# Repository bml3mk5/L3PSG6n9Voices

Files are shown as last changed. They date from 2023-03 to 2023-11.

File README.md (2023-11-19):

# PSG 6&9声カード for 日立ベーシックマスターレベル3

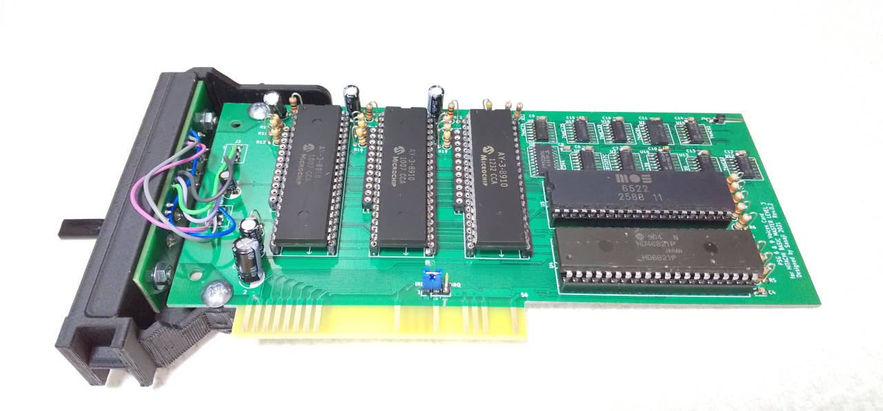
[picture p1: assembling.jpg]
Example of assembling


## フォルダ構成

    BackCover/ ..................... 背面カバーの3Dモデル
      L3BackSide2MJF-Resized.stl ... 背面カバーの3Dモデルファイル
      MegaZero2.0/ ................. Anycube MegaZero 2.0用
    Board/ ......................... 基板設計(KiCAD Version 5)
      main/ ........................ メイン基板
      side/ ........................ サブ基板(背面カバーに取り付ける基板)
      side_with_cover/ ............. 背面カバーを兼ねた基板

 * 3Dモデルから背面カバーを作ったときは、サブ基板を使用します。

-----
# PSG 6&9voices card for HITACHI BASIC MASTER LEVEL 3

## Folders:

    BackCover/ ..................... The 3D model of the back cover
      L3BackSide2MJF-Resized.stl ... The file of the back cover
      MegaZero2.0/ ................. For Anycube MegaZero 2.0
    Board/ ......................... Circuit board design(KiCAD Version 5)
      main/ ........................ The main board
      side/ ........................ The sub board (Attach to the back cover)
      side_with_cover/ ............. The side board which doubles as a back cover

 * When you made the back cover from 3D model, use the sub board.

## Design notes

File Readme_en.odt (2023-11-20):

# PSG6&9Voices Card for HITACHI BASIC MASTER LEVEL3

Designed by Sasaji 2021 Rev. 0.2

This is an extension card for HITACHI BASIC MASTER LEVEL3, markII and mark5. This is equipped with 3 PSGs and you can play with up to 9 voices.


Implementation

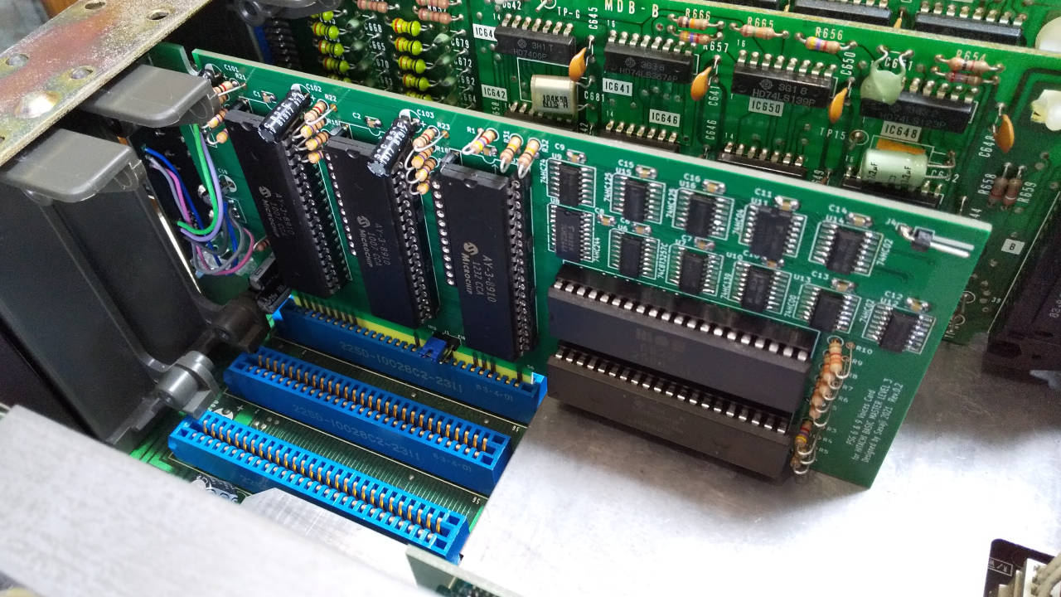
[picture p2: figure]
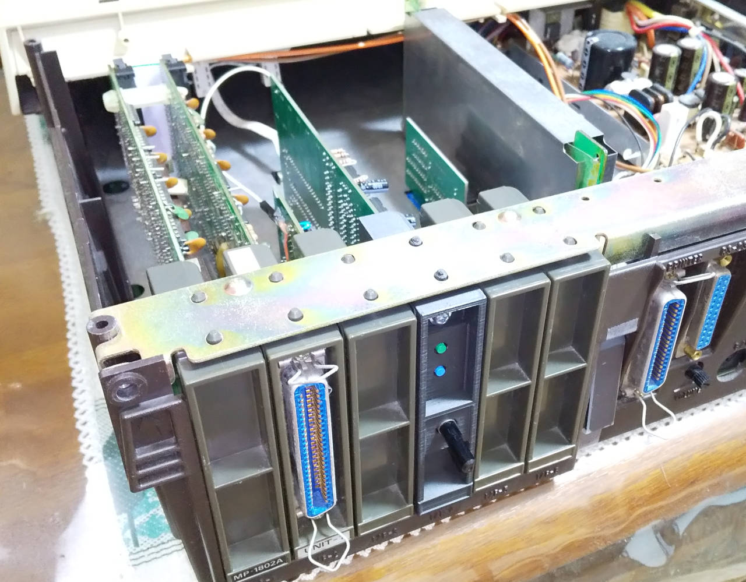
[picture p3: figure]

Installation

This card has two modes to control PSG via PIA and to do it via VIA.

PIA mode | This control two PSGs. You can play up to 6 voices. Supported games: Destroy Alien, The Cockpit
VIA mode | This control three PSGs. You can play up to 9 voices. Supported games: Skipper

You can toggle these modes using a I/O port by software, or buttons on the back side.

When specify from BASIC:

PIA: POKE &HFF34,0

VIA: POKE &HFF34,&H81

# I/O Ports

PIA Register

Address | D7 | D6 | D5 | D4 | D3 | D2 | D1 | D0 | R/W
$FF30 | DA7 | DA6 | DA5 | DA4 | DA3 | DA2 | DA1 | DA0 | R/W | PIA Data Register A Write to PSG
$FF31 | | | | | | | | | R/W | PIA Control Register A
$FF32 | x | x | x | x | x | SEL | BDIR | BC1 | R/W | PIA Data Register B PSG Bus Control
$FF33 | | | | | | | | | R/W | PIA Control Register B

When BDIR = 1 and BC1 = 1, latch register number on PSG.

When BDIR = 1 and BC1 = 0, write data to PSG.

When BDIR = 0 and BC1 = 1, read data from PSG.

SEL : Select PSG1 = 0, Select PSG2 = 1

PIA/VIA Select

Address | D7 | D6 | D5 | D4 | D3 | D2 | D1 | D0 | R/W
$FF34 ($FF35) | CLK | x | x | x | x | x | x | V/P | R/W

V/P … “0”:Select PIA, “1”:Select VIA

CLK … Select clock on PSG “0”: 1MHz “1”:2MHz

VIA Register

Address | D7 | D6 | D5 | D4 | D3 | D2 | D1 | D0 | R/W
$FF70 | x | x | x | PSG3 | PSG2 | PSG1 | BC1 | BDIR | R/W | ORB PSG Bus Control
$FF71 | DA7 | DA6 | DA5 | DA4 | DA3 | DA2 | DA1 | DA0 | R/W | ORA Write to PSG
$FF72 ~ $FF7F | | | | | | | | | | VIA Register See datasheet of VIA for details.

When BDIR = 1 and BC1 = 1, latch register number on PSG.

When BDIR = 1 and BC1 = 0, write data to PSG.

When BDIR = 0 and BC1 = 1, read data from PSG.

PSG1:Select PSG1=1

PSG2:Select PSG2=1

PSG3:Select PSG3=1

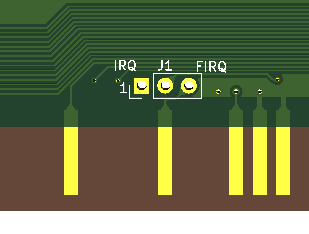
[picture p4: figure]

# Jumper Pin

This connect the interrupt signals from PIA and VIA to the CPU side.

Normally, short the IRQ side (1-2).

# The back cover Extended terminal

## PIA select button

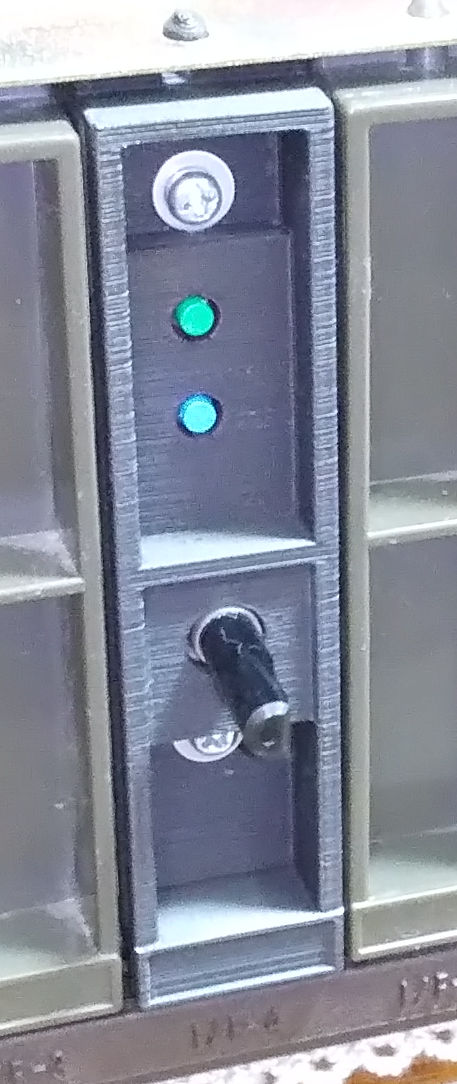
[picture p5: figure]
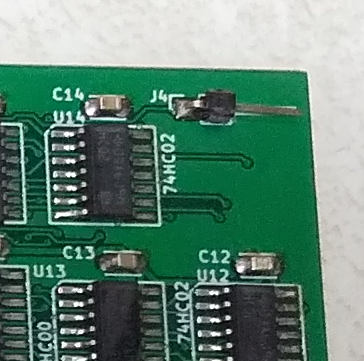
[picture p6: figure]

## VIA select button

## "H” level when PIA, "L” level when VIA. Sound volume

# Attention

- You cannot adjust the sound using the volume on the main board. Please use it on the back cover.
- The Kanji ROM card and VIA address are duplicated. When select the VIA side, don’t read from Kanji ROM or VIA port.
- This board is a prototype. No consideration is given to noise generated during use and deterioration over time.

## No warranty

We are not responsible for any damage caused by this card.

You use this card at your own risk.

## Web

This document and CAD data are opened on the web.

GitHub(https://github.com/bml3mk5/L3PSG6n9Voices)

or

http://s-sasaji.ddo.jp/bml3mk5/l3psg6n9.htm#board

Sasaji (sasaji@s-sasaji.ddo.jp)

http://s-sasaji.ddo.jp/bml3mk5/

(Twitter: https://twitter.com/bml3mk5)

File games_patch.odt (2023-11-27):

# いくつかのゲームはPSGカード用に修正が必要です。

以下のゲームは雑誌に掲載されたプログラムのままではPSGから音が出ません。 以下のように修正してください。

## 「デストロイエイリアン」

### 雑誌掲載のダンプリストを入力する際

$6003を1にする。

$614C,$614Dを$FF30にする。

$6F1F,$6F20を$FF30にする。

### すでにセーブしたプログラムがある場合

BASICから以下のように入力してください。

- リスト中のファイル名"DESTROY"はすでにセーブしている名前に変更してください。

NEWON17

LOADM"DESTROY"

POKE &H6003,1

POKE &H614C,&HFF

POKE &H614D,&H30

POKE &H6F1F,&HFF

POKE &H6F20,&H30

SAVEM"DESTROY",&H6000,&H762F,&H6000

#### ゲームをロードする際は、PSGカードをPIAモードに設定してください。

## 「スキッパー」

### 雑誌掲載のダンプリストを入力する際

$4B04番地を1にする。

### すでにセーブしたプログラムがある場合

BASICから以下のように入力してください。

- リスト中のファイル名"SKIPPER"はすでにセーブしている名前に変更してください。

NEWON3

LOADM"SKIPPER"

POKE &H4B04,1

SAVEM"SKIPPER",&H4B00,&H902F,&H4B00

#### ゲームをロードする際は、PSGカードをVIAモードに設定してください。

# Some games require patches for the PSG card.

In the following games, the PSG doesn't sound unless the patch is applied. Please correct it.

## “Destroy Alien”

### When you will input the dump list from the magazine:

Set 1 on $6003.

Set $FF30 on $614C and $614D.

Set $FF30 on $6F1F and $6F20.

### When you have the saved program:

Input following command on BASIC.

• Replace the file name "DESTROY" on the list to your saved name.

NEWON17

LOADM"DESTROY"

POKE &H6003,1

POKE &H614C,&HFF

POKE &H614D,&H30

POKE &H6F1F,&HFF

POKE &H6F20,&H30

SAVEM"DESTROY",&H6000,&H762F,&H6000

#### Set to PIA mode on the PSG card when loading the game.

## “Skipper”

### When you will input the dump list from the magazine:

Set 1 on $4B04.

### When you have the saved program:

Input following command on BASIC.

• Replace the file name "SKIPPER" on the list to your saved name.

NEWON3

LOADM"SKIPPER"

POKE &H4B04,1

SAVEM"SKIPPER",&H4B00,&H902F,&H4B00

#### Set to VIA mode on the PSG card when loading the game.

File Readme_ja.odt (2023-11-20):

# PSG6&9声カード for 日立ベーシックマスターレベル３

Designed by Sasaji 2021 Rev. 0.2

日立ベーシックマスターレベル３/マークII/マーク5用の拡張カードです。PSGを3つ搭載し最大9重和音で演奏できます。


実装例


実機に装着した状態

このカードには、PIAを経由してPSGを制御するモードと、VIAを経由してPSGを制御するモードがあります。

PIAモード | PSGを2つ制御します。最大6重和音で演奏できます。 対応している主なゲーム： 「デストロイエイリアン」「ザ・コックピット」
VIAモード | PSGを3つ制御します。最大9重和音で演奏できます。 対応している主なゲーム： 「スキッパー」

これらのモードは、ソフトウェアからI/Oポートを使うか、背面にあるボタンによって切り替えることができます。

BASICから指定する場合

PIA側に設定： POKE &HFF34,0

VIA側に設定： POKE &HFF34,&H81

# I/Oポート

PIAレジスタ

アドレス | D7 | D6 | D5 | D4 | D3 | D2 | D1 | D0 | R/W
$FF30 | DA7 | DA6 | DA5 | DA4 | DA3 | DA2 | DA1 | DA0 | R/W | PIAデータレジスタA PSGにデータ書き込み
$FF31 | | | | | | | | | R/W | PIA コントロールレジスタA
$FF32 | x | x | x | x | x | SEL | BDIR | BC1 | R/W | PIAデータレジスタB PSGバスコントロール
$FF33 | | | | | | | | | R/W | PIA コントロールレジスタB

BDIR = 1 かつ BC1 = 1 の時、PSGレジスタ選択

BDIR = 1 かつ BC1 = 0 の時、PSGデータ書き込み

BDIR = 0 かつ BC1 = 1 の時、PSGデータ読み出し

SEL : PSG1選択=0, PSG2選択=1

PIA/VIA選択レジスタ

アドレス | D7 | D6 | D5 | D4 | D3 | D2 | D1 | D0 | R/W
$FF34 ($FF35) | CLK | x | x | x | x | x | x | V/P | R/W

V/P … “0”:PIA選択、“1”:VIA選択

CLK … PSGクロック選択 “0”: 1MHzクロック “1”:2MHzクロック

VIAレジスタ

アドレス | D7 | D6 | D5 | D4 | D3 | D2 | D1 | D0 | R/W
$FF70 | x | x | x | PSG3 | PSG2 | PSG1 | BC1 | BDIR | R/W | ORB PSGバスコントロール
$FF71 | DA7 | DA6 | DA5 | DA4 | DA3 | DA2 | DA1 | DA0 | R/W | ORA PSGにデータ書き込み
$FF72 ~ $FF7F | | | | | | | | | | VIAレジスタ 詳細はVIAのデータシートを参照してください。

BDIR = 1 かつ BC1 = 1 の時、PSGレジスタ選択

BDIR = 1 かつ BC1 = 0 の時、PSGデータ書き込み

BDIR = 0 かつ BC1 = 1 の時、PSGデータ読み出し

PSG1:PSG1選択時=1

PSG2:PSG2選択時=1

PSG3:PSG3選択時=1

# ジャンパピン


PIAおよびVIAからの割り込み信号をCPU側に接続します。

通常はIRQ側(1-2)をショートするようにしてください。

# 背面カバー 拡張端子

## PIA側 選択ボタン


## VIA側 選択ボタン

## PIA選択中は"H” VIA選択中は"L” になります。 音量調節 ボリューム

# 使用上の注意

- 音量は本体内蔵のボリュームでは調節できません。背面カバーにあるボリュームを使用してください。
- 漢字ROMカードとVIAのアドレスが重複するため、漢字ROMカードを装着している状態でVIA側を使用する場合は、漢字ROMとVIAのリード操作は避けてください。
- この基板は試作品です。使用中に発生するノイズや経年劣化などに対しての考慮は全くしていませんので予めご了承ください。

## 免責事項

この基板によって発生したいかなる損害についても当方は一切責任を負いません。

この基板を使用するにあたってはすべて自己責任で行ってください。

## Webページ

この資料やCADデータなどを置いています。

GitHub(https://github.com/bml3mk5/L3PSG6n9Voices)

または

http://s-sasaji.ddo.jp/bml3mk5/l3psg6n9.htm#board

連絡先：

Sasaji (sasaji@s-sasaji.ddo.jp)

http://s-sasaji.ddo.jp/bml3mk5/

(Twitter: https://twitter.com/bml3mk5)

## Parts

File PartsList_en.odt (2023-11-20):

# PSG6&9Voices Card for HITACHI BASIC MASTER LEVEL3

Designed by Sasaji 2021 Rev. 0.2

Parts List

### The main board

Parts Number | Parts Name | Qty. | Description
C1~C16 | Ceramic Capacitor | 16 | 0.1uF (Bypass)
C19 | Electrolytic Capacitor | 1 | 1uF, 10V~
C100 | Electrolytic Capacitor | 1 | 100uF, 16V~ (Bypass)
C101~C103 | Electrolytic Capacitor | 3 | 22uF, 10V~ (Coupling)
C104 | Electrolytic Capacitor | 1 | 100uF, 10V~ (Coupling)
R1 | Carbon Resistor | 1 | 4.7KΩ, 1/4W~ (Pullup)
R3~R5 | Carbon Resistor | 3 | 4.7KΩ, 1/4W~ (Pulldown)
R6~R10 | Carbon Resistor | 5 | 3.3KΩ, 1/4W~ (Pulldown)
R11~R19 | Carbon Resistor | 9 | 470Ω, 1/4W~ (Analog sound)
R21~R24 | Carbon Resistor | 4 | 1KΩ, 1/4W~ (Analog sound)
R31~R32 | Carbon Resistor | 2 | 10KΩ, 1/4W~ (Pullup)
U1~U3 | PSG (or compatible IC) | 3 | AY-3-8910, AY-3-8913 or YM2149 DIP40pin or 24pin 600mil * Use the same type IC on U1~U3.
U4 | PIA | 1 | HD6821P or MC6821, DIP40pin 600mil
U5 | VIA | 1 | MCS6522 or R6522, DIP40pin 600mil
U6~U7 | CMOS Logic IC | 2 | 74CBT3257C, SOIC16pin
U8 | CMOS Logic IC | 1 | 74HC244, SOIC20pin
U9 | CMOS Logic IC | 1 | 74HC74, SOIC14pin
U10 | CMOS Logic IC | 1 | 74HC139, SOIC16pin
U11 | CMOS Logic IC | 1 | 74HC04, SOIC14pin
U12,U14 | CMOS Logic IC | 2 | 74HC02, SOIC14pin
U13 | CMOS Logic IC | 1 | 74HC00, SOIC14pin
U15,U16 | CMOS Logic IC | 2 | 74HC125, SOIC14pin
J1 | Jumper | 1 | Pin header 3pin x1 2.54mm pitch straight
| Jumper Pin | 1 | To short the J1
J2 | Wire cable | 3 | Connect to button on the sub board (J1)
J3 | Wire cable | 3 | Connect to volume on the sub board (J2)

Optional parts
J4 | Connector | 1 | Pin header 1pin x1 L angled (PIA/VIA select output)
| IC Socket | 5 | Use on U1~U5

### The sub board

Parts Number | Parts Name | Qty. | Description
SW1,SW2 | Push button | 2 | Tact switch (momentary) Phi is ~3.5mm, and the height of the key top is 4mm or more.
RV1 | Volume | 1 | 10KΩ Alpus RK09 Series
J1 | Wire cable | 3 | Connect to J2 on the main board
J2 | Wire cable | 3 | Connect to J3 on the main board

# Attention to build the board

### The capacitor near screw hole

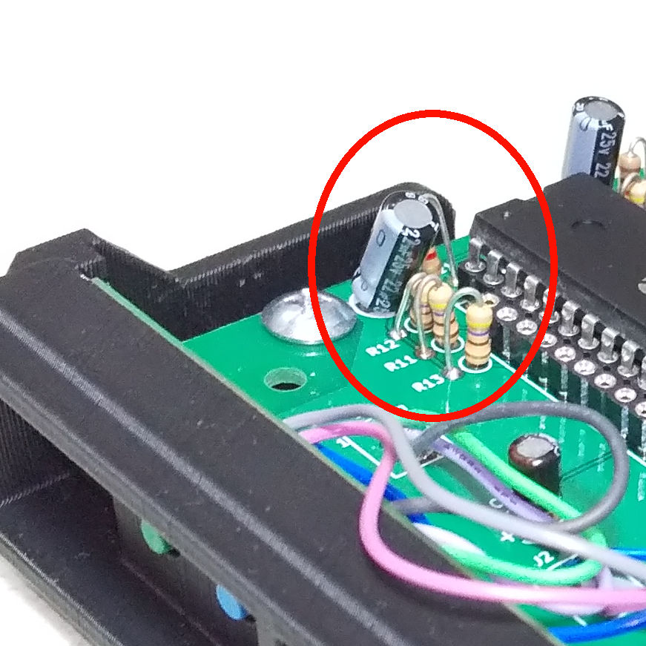
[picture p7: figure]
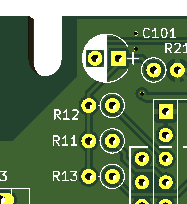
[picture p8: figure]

When attaching the C101, R11, R12, and R13 to the board, bend them slightly to avoid interference with the tapping screw and the adjacent expansion card.

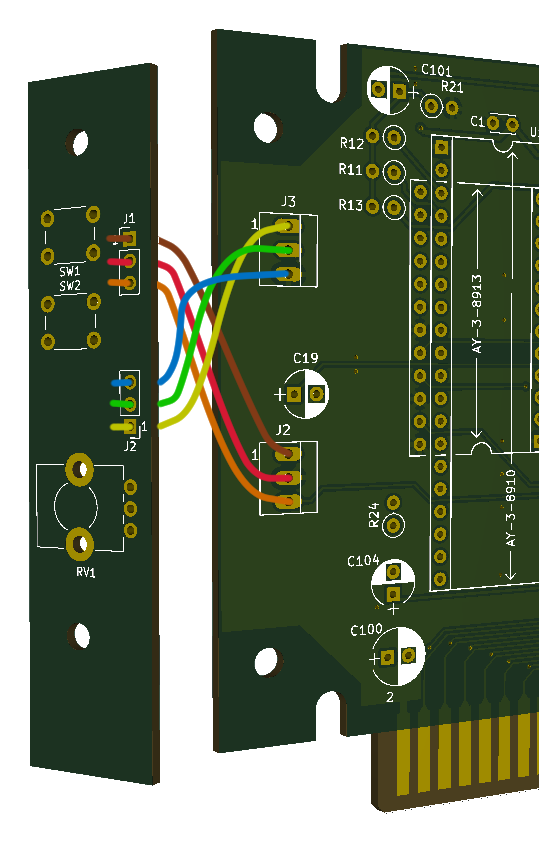
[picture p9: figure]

### Connect the main and sub board

Connect the main J2 <-> sub J1 and the main J3 <-> sub J2 with electric wires.

Match the main and sub pin numbers. When connected, the wires will cross each other.

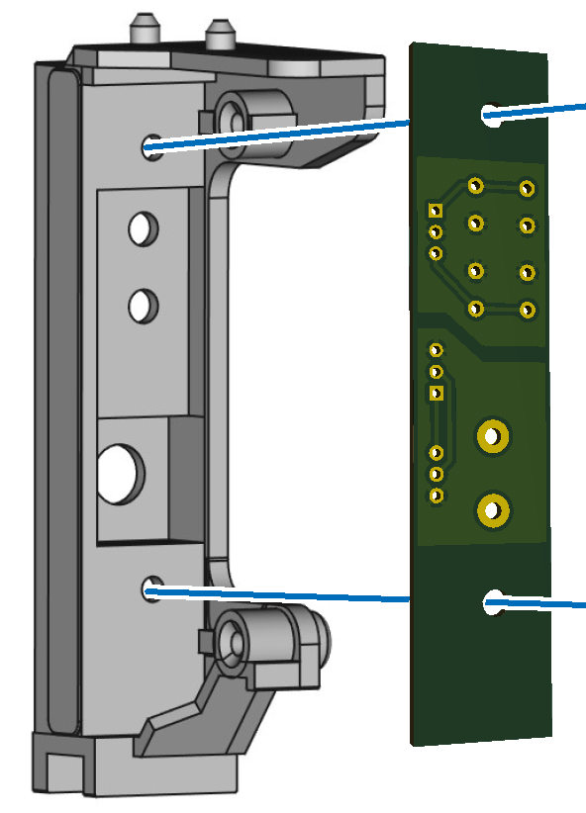
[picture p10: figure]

### Attach the sub board to the back cover

Before soldering electronic components, temporarily fix the components to the sub-board and check if they can be attached to the back cover in that state.

If the board does not fit all the way into the cover, cut the lower part of the sub board by about 5 mm.

After confirming the mounting of the board, solder it and fix it to the cover with M3 screws.

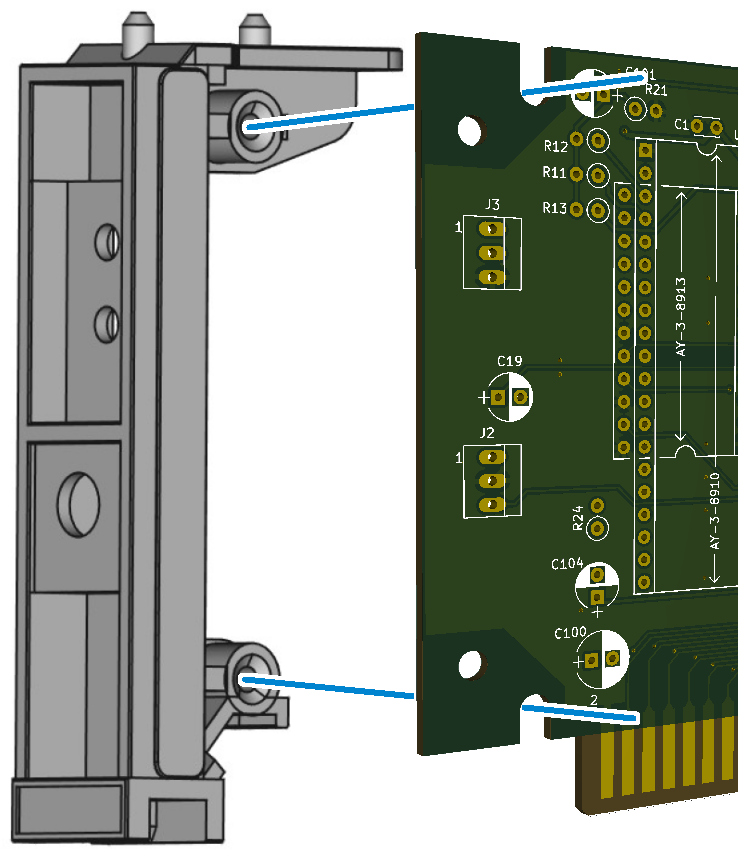
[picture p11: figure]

### Attach the main board to the back cover

Attach the main board and cover to the positions shown in the figure with tapping screws.

The back cover is fragile, so be careful and do not use too much force when tightening a screw.

### [Extra way] Use the black board as a back cover

The black board is used when you want to use it as a back cover as it is.

Connect to the main board using L-angled brackets and screws.

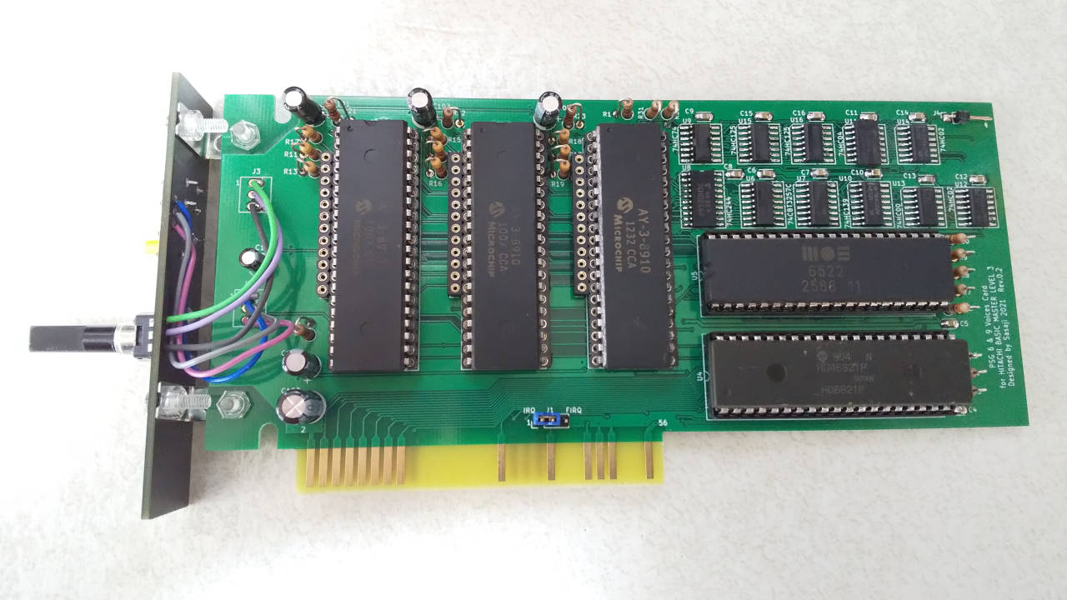
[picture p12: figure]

## No warranty

We are not responsible for any damage caused by this card.

You use this card at your own risk.

## Web

This document and CAD data are opened on the web.

GitHub(https://github.com/bml3mk5/L3PSG6n9Voices)

or

http://s-sasaji.ddo.jp/bml3mk5/l3psg6n9.htm#board

Sasaji (sasaji@s-sasaji.ddo.jp)

http://s-sasaji.ddo.jp/bml3mk5/

(Twitter: https://twitter.com/bml3mk5)

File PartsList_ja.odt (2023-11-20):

# PSG6&9声カード for 日立ベーシックマスターレベル３

Designed by Sasaji 2021 Rev. 0.2

# 部品表

●メイン基板

番号 | 部品名 | 数量 | 値など
C1~C16 | セラミックコンデンサ | 16 | 0.1uF （パスコン）
C19 | 電解コンデンサ | 1 | 1uF, 10V～
C100 | 電解コンデンサ | 1 | 100uF, 16V～ （パスコン）
C101~C103 | 電解コンデンサ | 3 | 22uF, 10V～ （カップリング）
C104 | 電解コンデンサ | 1 | 100uF, 10V～ （カップリング）
R1 | カーボン抵抗 | 1 | 4.7KΩ, 1/4W～ （プルアップ）
R3~R5 | カーボン抵抗 | 3 | 4.7KΩ, 1/4W～ （プルダウン）
R6~R10 | カーボン抵抗 | 5 | 3.3KΩ, 1/4W～ （プルダウン）
R11~R19 | カーボン抵抗 | 9 | 470Ω, 1/4W～ （アナログ音声）
R21~R24 | カーボン抵抗 | 4 | 1KΩ, 1/4W～ （アナログ音声）
R31~R32 | カーボン抵抗 | 2 | 10KΩ, 1/4W～ （プルアップ）
U1~U3 | PSG（または互換IC） | 3 | AY-3-8910, AY-3-8913, YM2149 のいずれか DIP40ピン または 24ピン600mil ※U1~U3は同じ型番のICを使用してください。
U4 | PIA | 1 | HD6821P, MC6821など, DIP40ピン600mil
U5 | VIA | 1 | MCS6522, R6522など, DIP40ピン600mil
U6~U7 | CMOSロジックIC | 2 | 74CBT3257C, SOIC16ピン
U8 | CMOSロジックIC | 1 | 74HC244, SOIC20ピン
U9 | CMOSロジックIC | 1 | 74HC74, SOIC14ピン
U10 | CMOSロジックIC | 1 | 74HC139, SOIC16ピン
U11 | CMOSロジックIC | 1 | 74HC04, SOIC14ピン
U12,U14 | CMOSロジックIC | 2 | 74HC02, SOIC14ピン
U13 | CMOSロジックIC | 1 | 74HC00, SOIC14ピン
U15,U16 | CMOSロジックIC | 2 | 74HC125, SOIC14ピン
J1 | ジャンパ | 1 | ピンヘッダ 3ピンx1列 2.54mmピッチ ストレート
| ジャンパピン | 1 | 上記ジャンパをショートさせるため
J2 | ケーブル | 3 | サブ基板の押しボタン(J1)と接続
J3 | ケーブル | 3 | サブ基板の可変抵抗(J2)と接続

以下の部品はオプション
J4 | コネクタ | 1 | ピンヘッダ 1ピンx1列 Lアングル （PIA/VIA選択出力）
| ICソケット | 5 | U1～U5用

●サブ基板

番号 | 部品名 | 数量 | 値など
SW1,SW2 | 押しボタンスイッチ | 2 | タクトスイッチ（モーメンタリ） Φ～3.5mm, キートップの高さは4mm以上あったほうが良い （秋月にあるTS-0606-F-Nなど）
RV1 | 可変抵抗 | 1 | 10KΩ アルプス電気 RK09シリーズ
J1 | ケーブル(押しボタン用) | 3 | メイン基板のJ2と接続
J2 | ケーブル(可変抵抗用) | 3 | メイン基板のJ3と接続

# 組み立て時の注意

### ネジ穴に近いコンデンサ

C101とR11,R12,R13を取り付ける際は、タッピンネジおよび隣接する拡張カードとの干渉を避けるため、少しななめに曲げてください。


### メイン基板とサブ基板の接続

メインのJ2 ⇔サブのJ1、メインのJ3 ⇔サブのJ2を電線で接続してください。

メインとサブのピン番号は合わせてください。接続すると電線はお互いにクロスする形になります。

### 背面カバーにサブ基板を取り付ける


電子部品をはんだ付けする前に、サブ基板に部品を仮止めし、その状態で背面カバーに装着できるかを確認してください。

基板がどうしてもカバー奥まで入らない場合は、サブ基板の下側部分5mmほど切断してください。

基板の装着を確認できたらはんだ付けをし、M3のネジでカバーに固定してください。


### 背面カバーにメイン基板を取り付ける

メイン基板とカバーを図の位置にタッピンネジで取り付けてください。

背面カバーはもろいため、ネジを止める際はゆっくりあまり力を入れないようにしてください。

### 【おまけ】黒い基板を背面カバーとして使う

黒い基板は、これをそのまま背面カバーにする場合に使用します。

メイン基板と黒い基板は、L字金具とネジを使用して接続してください。


## 免責事項

この基板によって発生したいかなる損害についても当方は一切責任を負いません。

この基板を使用するにあたってはすべて自己責任で行ってください。

## Webページ

この資料やCADデータなどを置いています。

GitHub(https://github.com/bml3mk5/L3PSG6n9Voices)

または

http://s-sasaji.ddo.jp/bml3mk5/l3psg6n9.htm#board

連絡先：

Sasaji (sasaji@s-sasaji.ddo.jp)

http://s-sasaji.ddo.jp/bml3mk5/

(Twitter: https://twitter.com/bml3mk5)

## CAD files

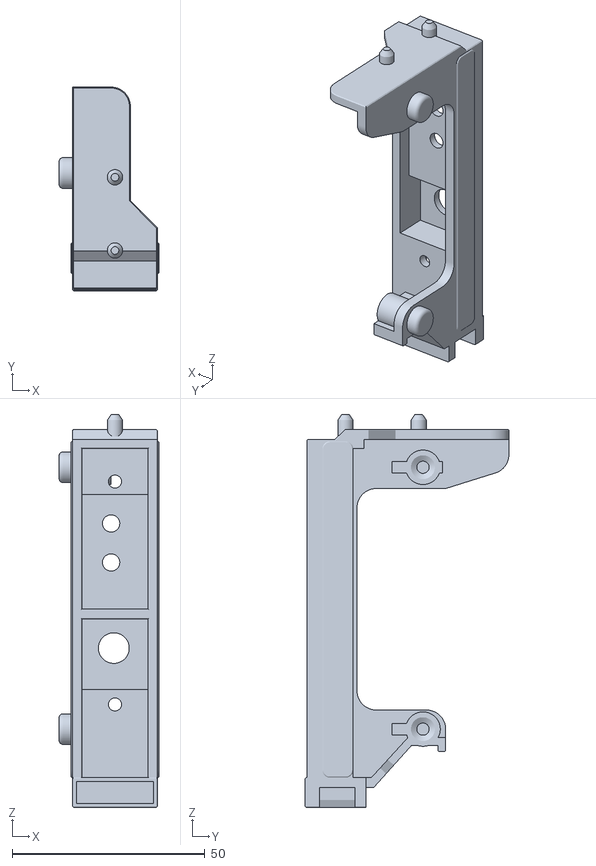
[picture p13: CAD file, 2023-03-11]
BackCover/L3BackSide2MJF-Resized.stl
25.9 x 52.9 x 102.0

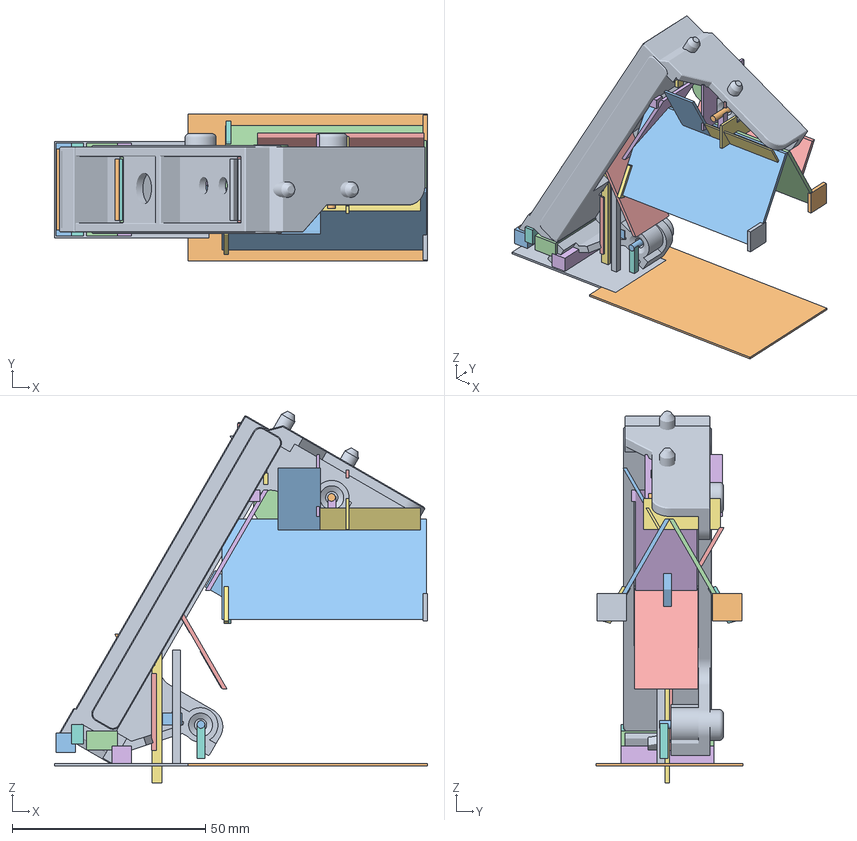
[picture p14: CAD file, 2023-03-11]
BackCover/MegaZero2.0/L3BackSide2MJF_h_mb.3mf
96.6 x 38.0 x 96.3 mm
L3BackSide2MJF-Body.stl
Square5-Body.stl
Diamond_h26-Body.stl(2)
Diamond_h26-Body.stl(1)
Diamond_h26-Body.stl(4)
Diamond_h26-Body.stl(3)
Square5-Body.stl(1)
Square5-Body.stl(2)
Square5-Body.stl(3)
Square5-Body.stl(4)
Square5-Body.stl(5)
Square5-Body.stl(6)
Diamond_h10-Body.stl
Square5-Body.stl(7)
Diamond_h10-Body.stl(1)
Square5-Body.stl(8)
Diamond_h10-Body.stl(2)
Diamond_h10-Body.stl(3)
Diamond_h20-Body.stl
Square5-Body.stl(9)
Square5-Body.stl(10)
Square5-Body.stl(11)
Diamond_h10-Body.stl(4)
Diamond_h10-Body.stl(5)
Diamond_h16-Body.stl
Diamond_h16-Body.stl(1)
Square5-Body.stl(12)
Square5-Body.stl(14)
Square5-Body.stl(15)
Square5-Body.stl(16)
Square5-Body.stl(17)
Square5-Body.stl(18)
Square5-Body.stl(19)
Square5-Body.stl(20)
Square5-Body.stl(21)
cylinder_r1_10-Body.stl(2)
Square5-Body.stl(22)
Square5-Body.stl(24)
Square5-Body.stl(23)
Square5-Body.stl(25)
Square5-Body.stl(26)
cylinder_r1_10-Body.stl
cylinder_r1_10-Body.stl(1)

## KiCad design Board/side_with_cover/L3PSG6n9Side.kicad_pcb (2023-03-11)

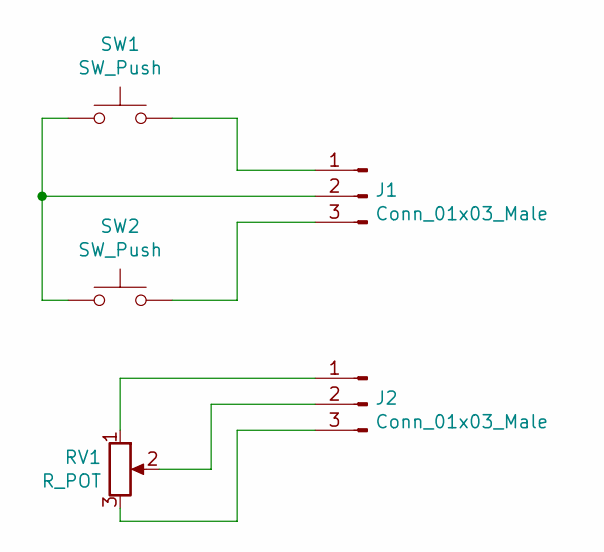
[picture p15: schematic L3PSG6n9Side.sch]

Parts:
J1, J2: Conn_01x03_Male; Pin_Header_Straight_1x03_Pitch2.54mm
RV1: R_POT; Potentiometer_Alps_RK09K_Horizontal
SW1, SW2: SW_Push; SW_PUSH_6mm

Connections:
unnamed: J1.1, SW1.2
unnamed: J1.2, SW1.1, SW2.1
unnamed: J1.3, SW2.2
unnamed: J2.1, RV1.1
unnamed: J2.2, RV1.2
unnamed: J2.3, RV1.3

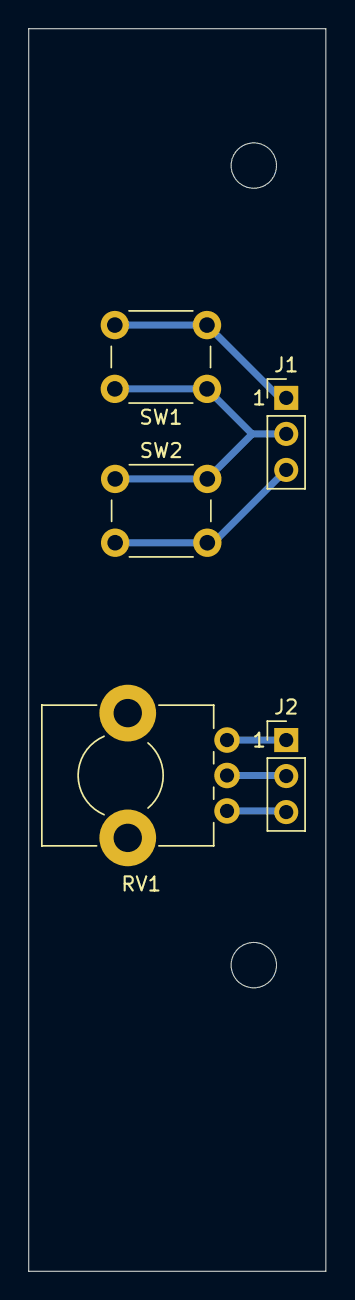
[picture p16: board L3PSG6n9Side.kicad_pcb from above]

Board: 2 copper layers, 21.0 x 87.6 mm, 5 parts (0 on the bottom side), 6 nets.

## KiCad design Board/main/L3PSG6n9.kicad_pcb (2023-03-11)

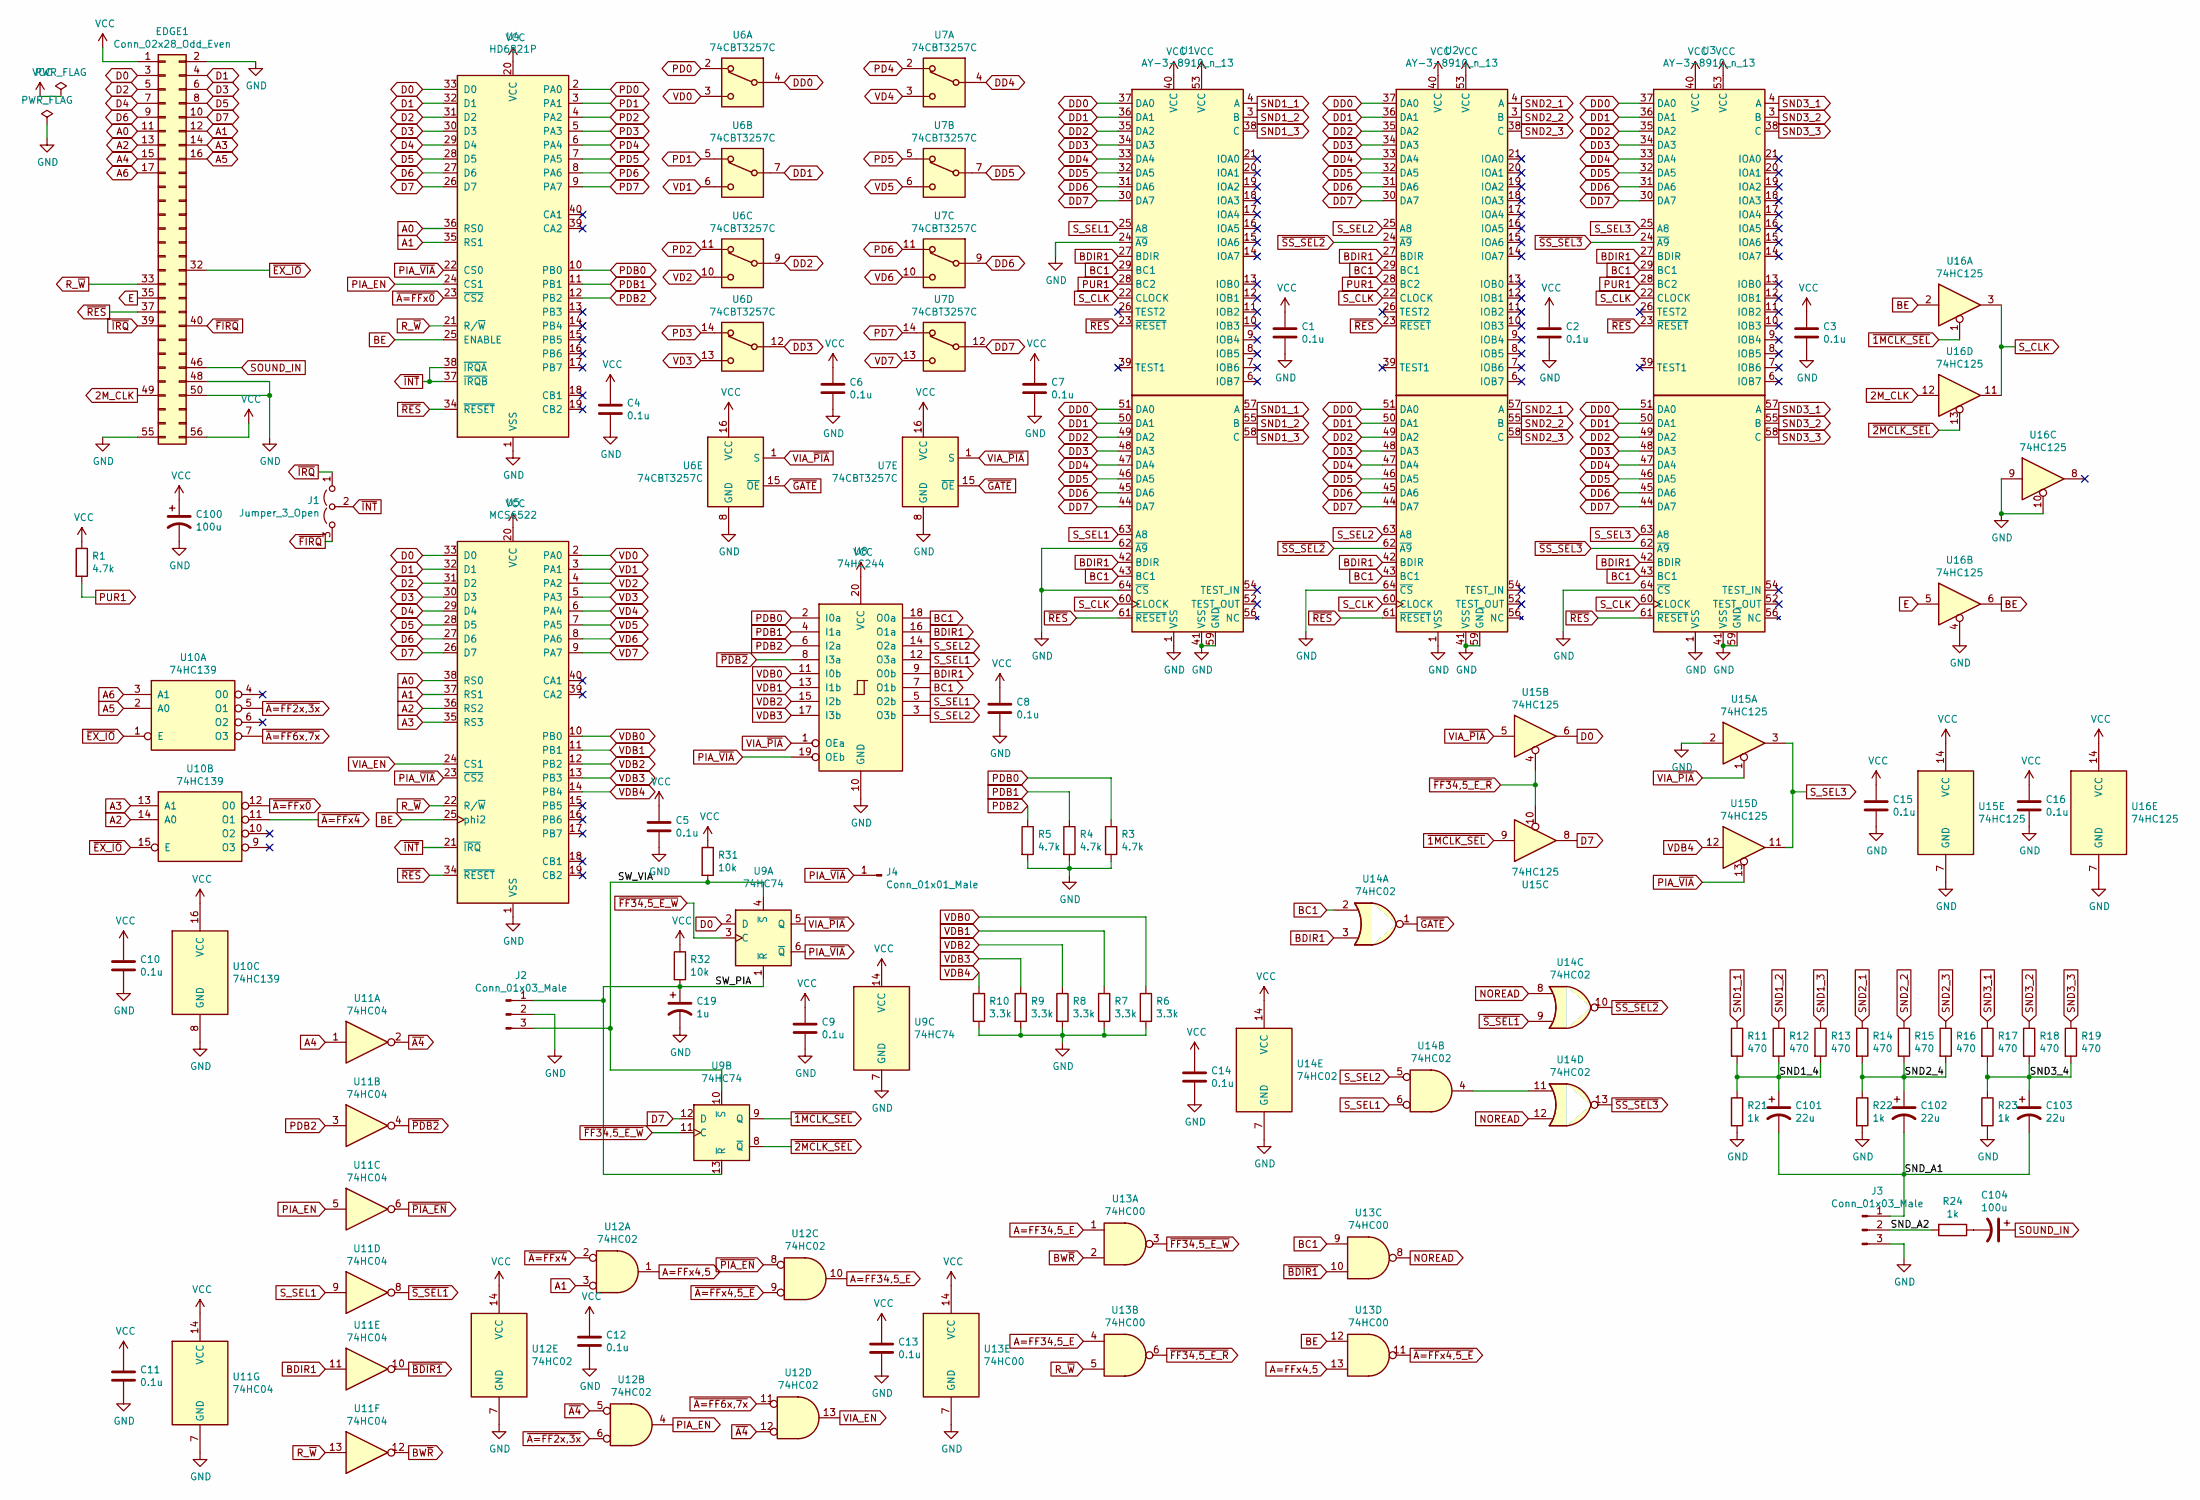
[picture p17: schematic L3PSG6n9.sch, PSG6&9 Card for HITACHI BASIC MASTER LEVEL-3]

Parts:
C1, C2, C3, C4, C5, C6, C7, C8, C9, C10, C11, C12, C13, C14, C15, C16: 0.1u; C_Disc_D3.0mm_W2.0mm_P2.50mm
C19: 1u; CP_Radial_D5.0mm_P2.50mm
C100: 100u; CP_Radial_D7.5mm_P2.50mm
C101, C102, C103: 22u; CP_Radial_D5.0mm_P2.50mm
C104: 100u; CP_Radial_D5.0mm_P2.50mm
EDGE1: Conn_02x28_Odd_Even; CardEdge56
J1: Jumper_3_Open; Pin_Header_Straight_1x03_Pitch2.54mm
J2, J3: Conn_01x03_Male; PINHEAD1-3
J4: Conn_01x01_Male; Pin_Header_Angled_1x01_Pitch2.54mm
R1, R3, R4, R5: 4.7k; R_Axial_DIN0207_L6.3mm_D2.5mm_P2.54mm_Vertical
R6, R7, R8, R9, R10: 3.3k; R_Axial_DIN0207_L6.3mm_D2.5mm_P2.54mm_Vertical
R11, R12, R13, R14, R15, R16, R17, R18, R19: 470; R_Axial_DIN0207_L6.3mm_D2.5mm_P2.54mm_Vertical
R21, R22, R23, R24: 1k; R_Axial_DIN0207_L6.3mm_D2.5mm_P2.54mm_Vertical
R31, R32: 10k; R_Axial_DIN0207_L6.3mm_D2.5mm_P2.54mm_Vertical
U1, U2, U3: AY-3-8910_n_13; DIP40n24
U4: HD6821P; DIP40
U5: MCS6522; DIP40
U6, U7: 74CBT3257C; SOIC-16
U8: 74HC244; SOIC-20
U9: 74HC74; SOIC-14
U10: 74HC139; SOIC-16
U11: 74HC04; SOIC-14
U12, U14: 74HC02; SOIC-14
U13: 74HC00; SOIC-14
U15, U16: 74HC125; SOIC-14

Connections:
2M_CLK: EDGE1.49, U16.12
/SND1_4: C101.1, R11.2, R12.2, R13.2, R21.1
/SND2_4: C102.1, R14.2, R15.2, R16.2, R22.1
/SND3_4: C103.1, R17.2, R18.2, R19.2, R23.1
/SND_A1: C101.2, C102.2, C103.2, J3.1
/SND_A2: J3.2, R24.2
/SW_PIA: C19.1, J2.1, R32.2, U9.1 (~R), U9.13 (~R)
/SW_VIA: J2.3, R31.2, U9.4 (~S), U9.10 (~S)
A0: EDGE1.11, U4.36 (RS0), U5.38 (RS0)
A1: EDGE1.12, U4.35 (RS1), U5.37 (RS1), U12.3
A2: EDGE1.13, U5.36 (RS2), U10.14 (A0)
A3: EDGE1.14, U5.35 (RS3), U10.13 (A1)
A4: EDGE1.15, U11.1
A5: EDGE1.16, U10.2 (A0)
A6: EDGE1.17, U10.3 (A1)
A=FF34,5_E: U12.10, U13.1, U13.4
A=FFx4,5: U12.1, U13.13
BC1: U1.29 (BC1), U1.43 (BC1), U2.29 (BC1), U2.43 (BC1), U3.29 (BC1), U3.43 (BC1), U8.7 (O1b), U8.18 (O0a), U13.9, U14.2
BDIR1: U1.27 (BDIR), U1.42 (BDIR), U2.27 (BDIR), U2.42 (BDIR), U3.27 (BDIR), U3.42 (BDIR), U8.9 (O0b), U8.16 (O1a), U11.11, U14.3
BE: U4.25 (ENABLE), U5.25 (phi2), U13.12, U16.2, U16.6
BW~R: U11.12, U13.2
D0: EDGE1.3, U4.33 (D0), U5.33 (D0), U9.2 (D), U15.6
D1: EDGE1.4, U4.32 (D1), U5.32 (D1)
D2: EDGE1.5, U4.31 (D2), U5.31 (D2)
D3: EDGE1.6, U4.30 (D3), U5.30 (D3)
D4: EDGE1.7, U4.29 (D4), U5.29 (D4)
D5: EDGE1.8, U4.28 (D5), U5.28 (D5)
D6: EDGE1.9, U4.27 (D6), U5.27 (D6)
D7: EDGE1.10, U4.26 (D7), U5.26 (D7), U9.12 (D), U15.8
DD0: U1.37 (DA0), U1.51 (DA0), U2.37 (DA0), U2.51 (DA0), U3.37 (DA0), U3.51 (DA0), U6.4
DD1: U1.36 (DA1), U1.50 (DA1), U2.36 (DA1), U2.50 (DA1), U3.36 (DA1), U3.50 (DA1), U6.7
DD2: U1.35 (DA2), U1.49 (DA2), U2.35 (DA2), U2.49 (DA2), U3.35 (DA2), U3.49 (DA2), U6.9
DD3: U1.34 (DA3), U1.48 (DA3), U2.34 (DA3), U2.48 (DA3), U3.34 (DA3), U3.48 (DA3), U6.12
DD4: U1.33 (DA4), U1.47 (DA4), U2.33 (DA4), U2.47 (DA4), U3.33 (DA4), U3.47 (DA4), U7.4
DD5: U1.32 (DA5), U1.46 (DA5), U2.32 (DA5), U2.46 (DA5), U3.32 (DA5), U3.46 (DA5), U7.7
DD6: U1.31 (DA6), U1.45 (DA6), U2.31 (DA6), U2.45 (DA6), U3.31 (DA6), U3.45 (DA6), U7.9
DD7: U1.30 (DA7), U1.44 (DA7), U2.30 (DA7), U2.44 (DA7), U3.30 (DA7), U3.44 (DA7), U7.12
E: EDGE1.35, U16.5
GND: C1.2, C2.2, C3.2, C4.2, C5.2, C6.2, C7.2, C8.2, C9.2, C10.2, C11.2, C12.2, C13.2, C14.2, C15.2, C16.2, C19.2, C100.2, EDGE1.2, EDGE1.48, EDGE1.50, EDGE1.55, J2.2, J3.3, R3.2, R4.2, R5.2, R6.2, R7.2, R8.2, R9.2, R10.2, R21.2, R22.2, R23.2, U1.1 (VSS), U1.24 (~A9), U1.41 (VSS), U1.59 (GND), U1.62 (~A9), U1.64 (~CS), U2.1 (VSS), U2.41 (VSS), U2.59 (GND), U2.64 (~CS), U3.1 (VSS), U3.41 (VSS), U3.59 (GND), U3.64 (~CS), U4.1 (VSS), U5.1 (VSS), U6.8 (GND), U7.8 (GND), U8.10 (GND), U9.7 (GND), U10.8 (GND), U11.7 (GND), U12.7 (GND), U13.7 (GND), U14.7 (GND), U15.2, U15.7 (GND), U16.4, U16.7 (GND), U16.9, U16.10
NOREAD: U13.8, U14.8, U14.12
unnamed: C104.2, R24.1
unnamed: U14.4, U14.11
PD0: U4.2 (PA0), U6.2
PD1: U4.3 (PA1), U6.5
PD2: U4.4 (PA2), U6.11
PD3: U4.5 (PA3), U6.14
PD4: U4.6 (PA4), U7.2
PD5: U4.7 (PA5), U7.5
PD6: U4.8 (PA6), U7.11
PD7: U4.9 (PA7), U7.14
PDB0: R3.1, U4.10 (PB0), U8.2 (I0a)
PDB1: R4.1, U4.11 (PB1), U8.4 (I1a)
PDB2: R5.1, U4.12 (PB2), U8.6 (I2a), U11.3
PIA_EN: U4.24 (CS1), U11.5, U12.4
PIA_~VIA: J4.1, U4.22 (CS0), U5.23 (~CS2), U8.19 (OEb), U9.6 (~Q), U15.13
PUR1: R1.2, U1.28 (BC2), U2.28 (BC2), U3.28 (BC2)
R_~W: EDGE1.33, U4.21 (R/~W), U5.22 (R/~W), U11.13, U13.5
SND1_1: R11.1, U1.4 (A), U1.57 (A)
SND1_2: R12.1, U1.3 (B), U1.55 (B)
SND1_3: R13.1, U1.38 (C), U1.58 (C)
SND2_1: R14.1, U2.4 (A), U2.57 (A)
SND2_2: R15.1, U2.3 (B), U2.55 (B)
SND2_3: R16.1, U2.38 (C), U2.58 (C)
SND3_1: R17.1, U3.4 (A), U3.57 (A)
SND3_2: R18.1, U3.3 (B), U3.55 (B)
SND3_3: R19.1, U3.38 (C), U3.58 (C)
SOUND_IN: C104.1, EDGE1.46
S_CLK: U1.22 (CLOCK), U1.60 (CLOCK), U2.22 (CLOCK), U2.60 (CLOCK), U3.22 (CLOCK), U3.60 (CLOCK), U16.3, U16.11
S_SEL1: U1.25 (A8), U1.63 (A8), U8.5 (O2b), U8.12 (O3a), U11.9, U14.6
S_SEL2: U2.25 (A8), U2.63 (A8), U8.3 (O3b), U8.14 (O2a), U14.5
S_SEL3: U3.25 (A8), U3.63 (A8), U15.3, U15.11
VCC: C1.1, C2.1, C3.1, C4.1, C5.1, C6.1, C7.1, C8.1, C9.1, C10.1, C11.1, C12.1, C13.1, C14.1, C15.1, C16.1, C100.1, EDGE1.1, EDGE1.56, R1.1, R31.1, R32.1, U1.40 (VCC), U1.53 (VCC), U2.40 (VCC), U2.53 (VCC), U3.40 (VCC), U3.53 (VCC), U4.20 (VCC), U5.20 (VCC), U6.16 (VCC), U7.16 (VCC), U8.20 (VCC), U9.14 (VCC), U10.16 (VCC), U11.14 (VCC), U12.14 (VCC), U13.14 (VCC), U14.14 (VCC), U15.14 (VCC), U16.14 (VCC)
VD0: U5.2 (PA0), U6.3
VD1: U5.3 (PA1), U6.6
VD2: U5.4 (PA2), U6.10
VD3: U5.5 (PA3), U6.13
VD4: U5.6 (PA4), U7.3
VD5: U5.7 (PA5), U7.6
VD6: U5.8 (PA6), U7.10
VD7: U5.9 (PA7), U7.13
VDB0: R6.1, U5.10 (PB0), U8.11 (I0b)
VDB1: R7.1, U5.11 (PB1), U8.13 (I1b)
VDB2: R8.1, U5.12 (PB2), U8.15 (I2b)
VDB3: R9.1, U5.13 (PB3), U8.17 (I3b)
VDB4: R10.1, U5.14 (PB4), U15.12
VIA_EN: U5.24 (CS1), U12.13
VIA_~PIA: U6.1 (S), U7.1 (S), U8.1 (OEa), U9.5 (Q), U15.1, U15.5
~1MCLK_SEL: U9.9 (Q), U15.9, U16.1
~2MCLK_SEL: U9.8 (~Q), U16.13
~A4: U11.2, U12.5, U12.12
~A=FF2x,3x: U10.5 (O1), U12.6
~A=FF6x,7x: U10.7 (O3), U12.11
~A=FFx0: U4.23 (~CS2), U10.12 (O0)
~A=FFx4: U10.11 (O1), U12.2
~A=FFx4,5_E: U12.9, U13.11
~BDIR1: U11.10, U13.10
~EX_IO: EDGE1.32, U10.1 (E), U10.15 (E)
~FF34,5_E_R: U13.6, U15.4, U15.10
~FF34,5_E_W: U9.3 (C), U9.11 (C), U13.3
~FIRQ: EDGE1.40, J1.3 (B)
~GATE: U6.15 (~OE), U7.15 (~OE), U14.1
~INT: J1.2 (C), U4.37 (~IRQB), U4.38 (~IRQA), U5.21 (~IRQ)
~IRQ: EDGE1.39, J1.1 (A)
~PDB2: U8.8 (I3a), U11.4
~PIA_EN: U11.6, U12.8
~RES: EDGE1.37, U1.23 (~RESET), U1.61 (~RESET), U2.23 (~RESET), U2.61 (~RESET), U3.23 (~RESET), U3.61 (~RESET), U4.34 (~RESET), U5.34 (~RESET)
~SS_SEL2: U2.24 (~A9), U2.62 (~A9), U14.10
~SS_SEL3: U3.24 (~A9), U3.62 (~A9), U14.13
~S_SEL1: U11.8, U14.9

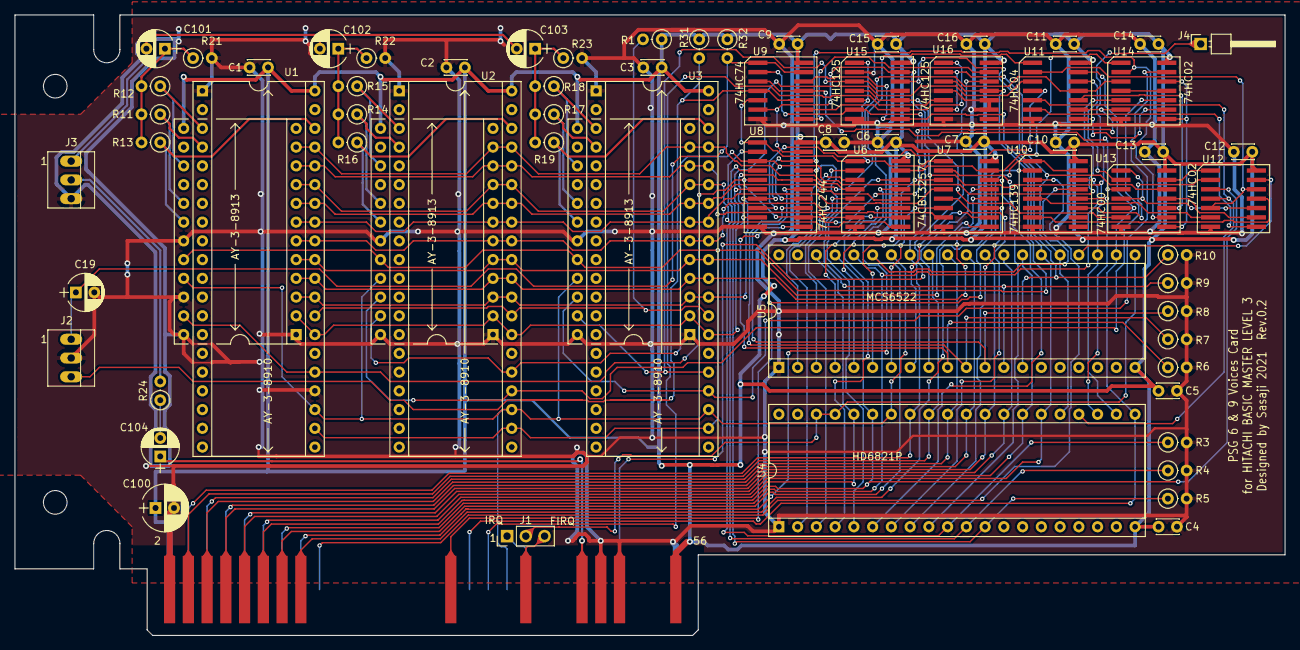
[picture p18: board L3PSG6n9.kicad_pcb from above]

Board: 2 copper layers, 172.1 x 84.1 mm, 68 parts (0 on the bottom side), 109 nets.

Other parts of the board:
T: T
